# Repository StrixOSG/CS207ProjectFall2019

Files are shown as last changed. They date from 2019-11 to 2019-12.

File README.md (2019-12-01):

# Improved Soil Moisture Sensor [v1.0]

<p align="center">
  <a href="#repository-contents">Repository Contents</a> •
  <a href="#materials">Materials</a> •
  <a href="#software-requirements">Software Requirements</a> •
  <a href="#build-instructions">Build Instructions</a> •
  <a href="#usage">Usage</a> •
  <a href="#video">Video</a> •
  <a href="#team">Team</a> •
  <a href="#credits">Credits</a>
</p>

<p align="center">
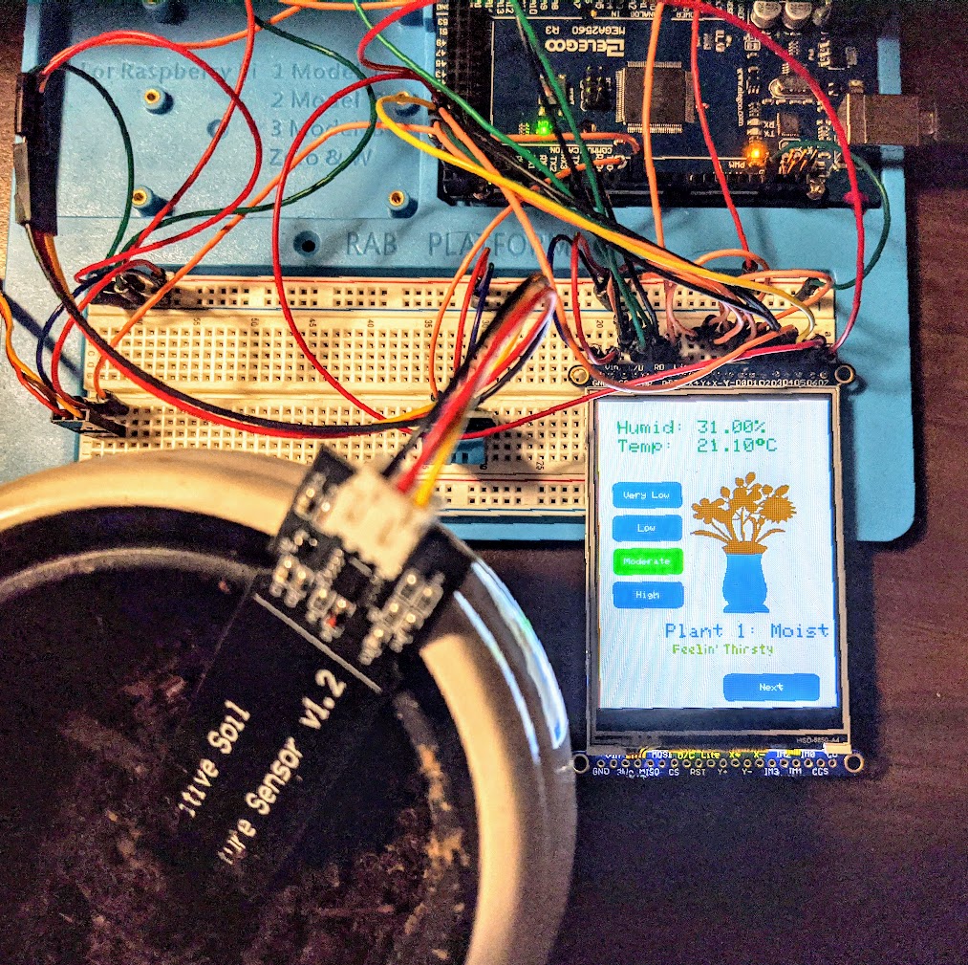
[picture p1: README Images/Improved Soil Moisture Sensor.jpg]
 
</p>

This project aims at making the soil moisture sensor project more practical (not necessarily cheaper) than the traditional (or original as I'll refer to it) project that has been done many times with a few LED indicators. To try and improve it, the LEDs are replaced by a 3.2" touchscreen display that can switch between plants depending on the amount of soil moisture sensors connected. Additionally, it can display the approximate temperature and humidity of the room as well as auto-water your plant by tipping over a small cup of water when attached to the servo. The touchscreen displays the temperature, humidity, and current soil moisture level of the plants, indicated by the 4 status' Wet, Damp, Moist, and Dry and an image of a plant that becomes more or less blue depending on the status. 

Repository Contents
============
* **/Bitmap Images** - Contains the .BMP files that were converted to code and used in the project and .psd (Photoshop CS6) files have been included for easy of modification if you desire to do so
* **/Hardware Diagrams** - .fzz (Fritzing files) and .jpg's that show the hardware and how it was wired
* **/Source Code** - Includes 2 folders, the original project that was built first as a test and the improved project
  * **/Source Code/ImprovedSoilMoistureSensor** - Contains the .cpp and .c files needed to run the improved project
  * **/Source Code/OriginalSoilMoistureSensor** - Contains the .cpp and .c files needed to run the original project

Materials
=========
**Original Project:**
* 1 x [Arduino UNO R3](https://store.arduino.cc/usa/arduino-uno-rev3)
* 4 x 220ohm Resistors
* 4 x LEDs (2 Green and 2 Red, or some way to differentiate Wet or Dry)

**Improved Project:**
* 1 x [3.2” TFT LCD with Touchscreen Breakout Board w/microSD socket](https://www.adafruit.com/product/1743)
* 1 x SG90 Micro Servo
* 1 x Small Plastic Cup (I just used a junior red solo cup)
* 1 x Servo Attachment (To tip the cup and not spill water everywhere)
* 1 x [Elegoo MEGA 2560 R3](https://www.amazon.ca/gp/product/B01H4ZLZLQ) (Note: An Arduino instead of an Elegoo will work, it's just more expensive)
* 1 x DHT11 (Temperature & Humidity Sensor)

**Materials In Common:**
* Several Jumper Wires (20 - 40)
* Breadboard
* 2 x [Capacitive Soil Moisture Sensors v1.2](https://www.amazon.ca/gp/product/B07H3P1NRM/ref=ppx_yo_dt_b_asin_title_o04_s00?ie=UTF8&psc=1)
* Several Male Header Pins

I bought a [ELEGOO UNO Project Super Starter Kit](https://www.amazon.ca/Elegoo-Project-Starter-Tutorial-Arduino/dp/B01D8KOZF4), which contained a lot of the components such as the Jumper Wires, Breadboard, Header Pins, DHT11, SG90 Micro Servo, Resistors, UNO R3, and LEDs.

Software Requirements
============

### Original Project:
None yay!

### Improved Project:
**Arduino Libraries:**
* Wire - Standard Library (just include it)
* Servo - Standard Library (just include it)
* [Adafruit GFX](https://github.com/adafruit/Adafruit-GFX-Library) 
* [Adafruit TFTLCD](https://github.com/adafruit/TFTLCD-Library)
* [Adafruit Touchscreen](https://github.com/adafruit/Adafruit_TouchScreen)
* [Adafruit DHT](https://github.com/adafruit/DHT-sensor-library)

**Software:**
  * [Img2Code](https://github.com/ehubin/Adafruit-GFX-Library/tree/master/Img2Code) - Adafruit Java Application that allows you to convert from a BMP image to code.
    * Resource on how to use it - [Electronics Lab Tutorial](https://www.electronics-lab.com/project/display-custom-bitmap-graphics-on-an-arduino-touch-screen-and-other-arduino-compatible-displays/)
    * I had some issues running this program (on Windows at least). I had to create a gradle.properties file in the Img2Code folder downloaded from the GitHUb, and point it to my JDK with "org.gradle.java.home=C:\\Program Files\\Java\\jdk1.8.0_191". After this, I ran the ./gradlew build and then ./gradlew run in the cmd prompt in the Img2Code directory and it worked. If you run into problems, the GitHub doesn't tell you any of this though, so if there is any other software for converting from a BMP image to code then don't be afraid to try it.

Build Instructions
==================
### Original Project:
For this project, you can use an UNO or a Mega. Fair warning that this project does not translate very well to the improved version. The point of setting this project up is to test the Mega, and the Soil Moisture Sensors and establish some simpler code to work off of.

#### Wiring:
* Wire the negative legs of the green LEDs to digital pins 3 and 5, and the red LEDs to digital pins 2 and 4. 
* Having some resistors (220ohm) connected to each of the positive legs of the LEDs is a good idea, just so they don't burn out as fast. The other side of the resistor should go to ground.
* The AOUT (Analog Out) pins on the soil moisture sensors should be connected to pins A0 and A1. Then the VCC's to 5V, and GND's to the GND.
* More details including diagrams (except for the above specified digital and analog pins to connect to) can be found [here](https://www.elithecomputerguy.com/2019/07/soil-moisture-sensor-led-alert-with-arduino-uno/), where the project was originally obtained from. Code for the idea of splitting the soil moisture values into 4 (Dry, Damp, Moist, and Dry) can be found [here](https://github.com/GadgetReboot/Arduino/blob/master/Uno/SSD1306_Soil_Meter/SSD1306_Soil_Meter.ino)

### Improved Project:
Now we get into the improvements. Like I mentioned in the Original Project's build instructions, almost everything changes except that we use the Mega and Soil Moisture Sensors.

#### Part Setup & Prep Work:
* The first step, is to solder on some male header pins to the 8-bit side of the 3.2" TFT Touchscreen. Be careful that it's not the SPI (Serial Peripheral Interface) side. [Adafruit](https://learn.adafruit.com/adafruit-2-dot-8-color-tft-touchscreen-breakout-v2/pinouts) has great detailed information about the differences between the two, but essentially it comes down to speed and how many pins you have. Since we have the Mega, we don't have to worry about using more pins so 8-bit mode is what is used for this project. SPI uses less pins, but it's 2 - 4 times slower than 8-bit mode at updating the touchscreen display.
  * Note: One problem encountered was that the pins weren't soldered well enough, which caused some issues when testing if the touchscreen was connected and working.

<p align="center">
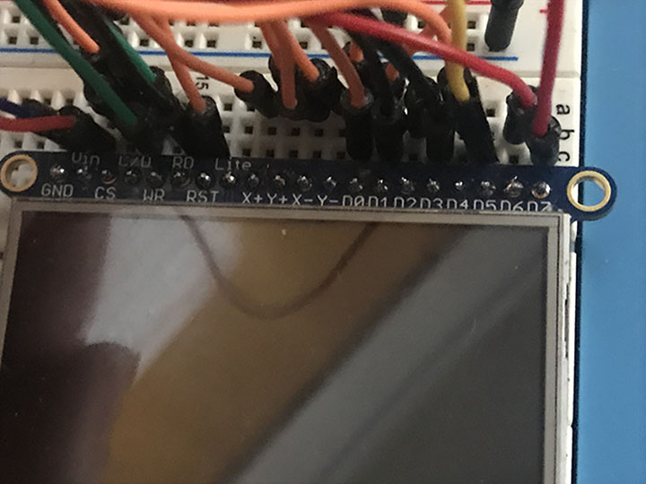
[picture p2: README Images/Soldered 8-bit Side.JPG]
 
</p>

* Next, the servo needs 3 male header pins.
* Lastly, attach a servo attachment to a junior red solo cup. I suggest zip ties and glue to ensure that the attachment stays in-place, so it remains securely attached to the cup while being tipped. Then attach the servo to some vertical base so that you don't have to hold it while it tips the cup. I attached it to a swiss rolls dessert box that I weighted down by again zip tying it to the box. This part needs improvement, because in the demo video you'll notice it begins to slip when filling the cup up with water.

<p align="center">
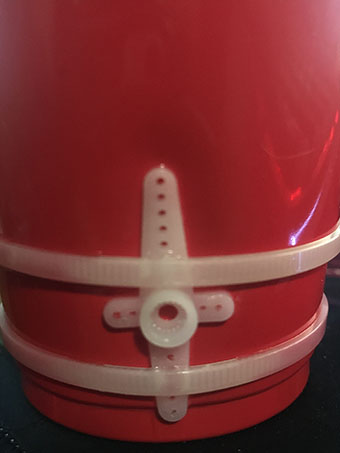
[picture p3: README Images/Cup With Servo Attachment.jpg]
 
</p>

#### Wiring:
* There isn't anything special with the wiring, except where the pins go. Just in case the Fritzing diagrams below aren't clear enough to follow here's the pins:

* Touchscreen (8-bit mode):
    * D0,XP to digital pin 22
    * D1,YM to digital pin 23
    * D2 to digital pin 24
    * D3 to digital pin 25
    * D4 to digital pin 26
    * D5 to digital pin 27
    * D6 to digital pin 28
    * D7 to digital pin 29
    * CS,YP to analog pin 3
    * C/D,XM to analog pin 2
    * WR to analog pin 1
    * RD to analog pin 0
    * RST to reset pin
    
    * Soil Moisture Sensors to analog pins 6 and 7
    * Temp & Humidity Sensor to digital pin 2
    * Servo to digital pin 3

* WARNING: Adafruit's tutorial states that the RST Pin can be A4 or another pin, but in my case this caused the touchscreen to not be read properly, so I connected it to the reset pin on the Mega.
* The XP, YM, YP, XM are the touchscreen's resistive sensor pins (detects touch) and they are to be connected to D0, D1, C/D, and CS respectively, so they all go to the same pins, 22, 23, A3, and A2 respectively.
* The soil moisture sensor, we setup in the original project, it is the same except which analog pins it connects to. 
* The servo's red wire goes to 5v, and black to GND. 
* The DHT11 (temp & humidity) sensor can be either 4 or 3 pins, if it does have 4 (unlike the one used in the project) then ignore one of the pins (search for your sensors pin layout to determine which pin this is). On the 3 pin sensor for this project, the ground is the right pin, middle is the data pin, and the left is the ground.

**Breadboard Diagram**

<p align="center">
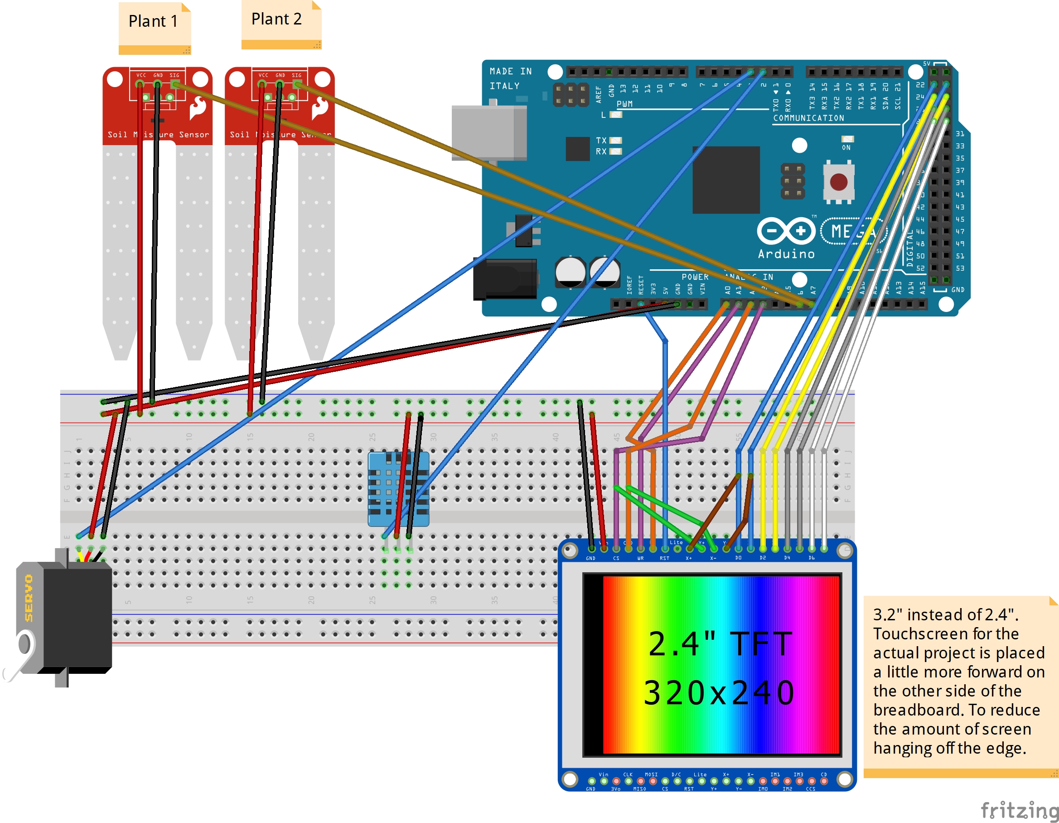
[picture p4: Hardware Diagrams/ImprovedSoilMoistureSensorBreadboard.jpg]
 
</p>

**Schematic Diagram**

<p align="center">
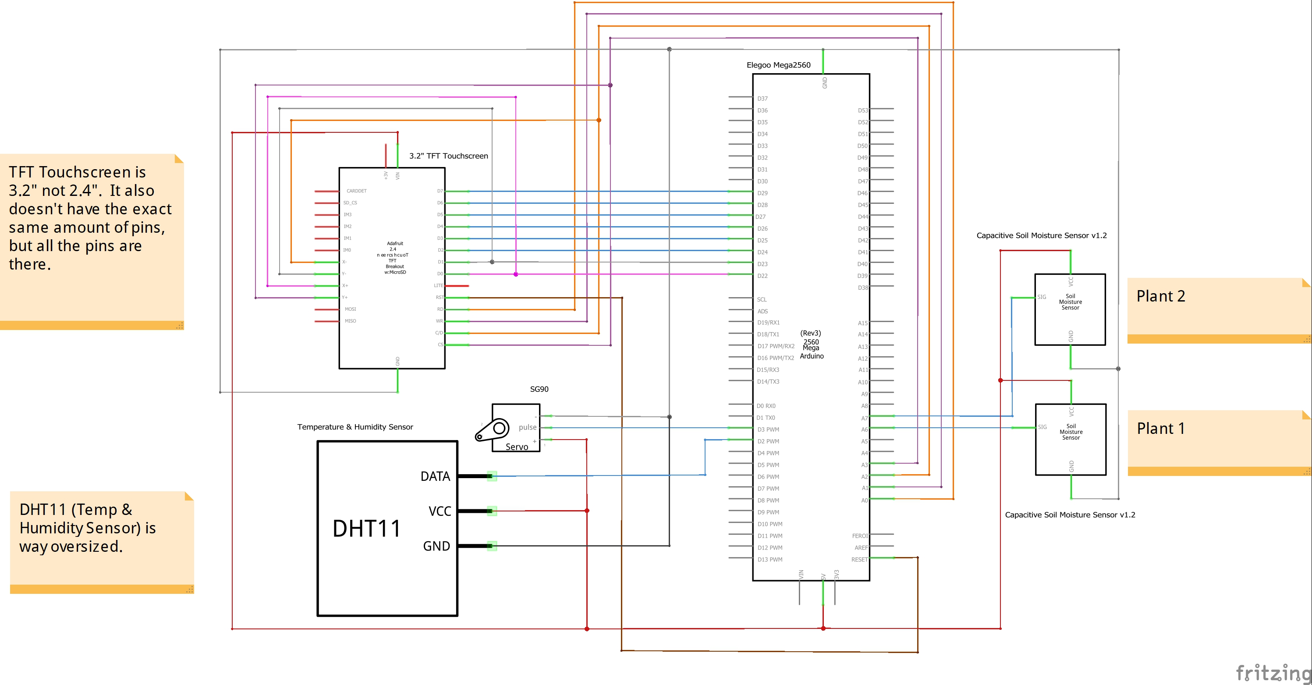
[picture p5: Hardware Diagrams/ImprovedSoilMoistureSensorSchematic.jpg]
 
</p>

Usage
=====
First step is to ensure that everything is wired and built properly.

### Original Project:
 1. Download the [original soil moisture sensor project folder](https://github.com/mattiasjahnke/arduino-projects).
 2. Open it in Arduino and run it on the device.
 3. Place soil moisture sensors in plants. Or grasp one of the soil moisture sensors in your hand and eventually the green LED should turn on, because your hand is damp or moist instead of dry when its not in anything.

### Improved Project:
 1. Download the [improved soil moisture sensor project folder](https://github.com/mattiasjahnke/arduino-projects).
 2. Open it in Arduino and run it on the device.
 3. Temperature and Humidity should be visible at the top of the screen.
 4. The visual state (partial or fully blue plant image) and text state (Wet, Damp, Moist, Dry) of the soil should be visible in the middle right of the screen. This changes based on how wet or dry the soil is.
 5. Plant moisture categories (Very Low, Low, Moderate, High) should be displayed on the left side of the screen, and status (I'm Drownin", "I'm Starting To Drown", "Tad too Much Water", "Ah. Just Right", "Feelin' Thirsty", "I NEED WATER SANDY", "I NEEEED ITTTT) should be below the soil moisture status.
 
  Note: Plant moisture categories can be found here: https://www.acurite.com/media/manuals/01410M-instructions.pdf
        0-20% (Very Low), 21-40% (Low), 41-60% (Moderate), 61-80+% (High)
        
 5. Tap the next button to switch to plant 2 (the other soil moisture sensor), and it's state should be displayed.
 6. The next button should disappear, and previous button should be on the other side of the screen.
 7. Changing the plant moisture category changes the status of your plant (if it needs more or less moisture). This is so it can be customized to fit the needs of your plant since not all plants require equal amounts of watering.
 8. Lastly, you can switch back and forth and monitor your plants water levels, and the temperature and humidity of the room :)

Video
=====

Improved Arduino Soil Moisture Sensor YouTube Video (http://www.youtube.com/watch?v=PviWJTjPKCI "Improved Arduino Soil Moisture Sensor - CS207 Fall 2019")

Team
=====
Mattthew Hamilton - I'm the only one on the team.

Credits
=======
* Jeff Bishop (A.K.A. Eli The Computer Guy) for inspiring the original project -  https://www.elithecomputerguy.com/2019/07/soil-moisture-sensor-led-alert-with-arduino-uno/

* Soil moisture sensor, mapping different moisture levels
  https://github.com/GadgetReboot/Arduino/blob/master/Uno/SSD1306_Soil_Meter/SSD1306_Soil_Meter.in
  Code by GitHub user: GadgetReboot

* Basic touchscreen code, setup, initialization, etc.
  https://github.com/adafruit/TFTLCD-Library
  Code by: Adafruit

* Bitmap image drawing code
  https://www.electronics-lab.com/project/display-custom-bitmap-graphics-on-an-arduino-touch-screen-and-other-arduino-compatible-displays/
  Code by: Nick Koumaris

* Button code
  https://learn.adafruit.com/arduin-o-phone-arduino-powered-diy-cellphone/arduin-o-phone-sketch
  Code by: Adafruit

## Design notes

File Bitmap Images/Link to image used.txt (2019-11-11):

Flower Vase - https://svgsilh.com/ff5722/image/147218.html

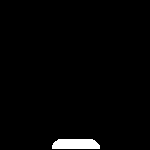
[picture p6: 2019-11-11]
Bitmap Images/SoilMoistureMeterDry.bmp

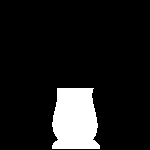
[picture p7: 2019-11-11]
Bitmap Images/SoilMoistureMeterMoist.bmp

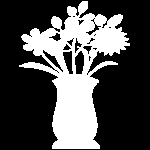
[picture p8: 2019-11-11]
Bitmap Images/SoilMoistureMeterBackground.bmp

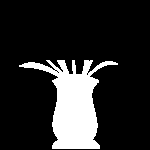
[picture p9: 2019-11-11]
Bitmap Images/SoilMoistureMeterDamp.bmp

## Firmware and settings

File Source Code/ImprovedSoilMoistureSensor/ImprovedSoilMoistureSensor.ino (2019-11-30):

/*

Project Summary:
This program will read the analog moisture level of
2 capactive soil moisture sensors, and a digital
temperature and humidity sensor. It then outputs
these readings to a touch screen, and there are buttons
to switch bettween the two plants (soil moisture sensors).
A servo is also attached that will tip a cup to fill one
of the plants with water if it needs it.

Parts:
- 2 x Soil moisture sensors
- 1 x 3.2" TFT Resistive Touchscreen
- 1 x DH11 Temp & Humidity Sensor
- 1 x SG90 Servo

Connections: 
- Touchscreen (8-bit mode):
    D0,XP to digital pin 22
    D1,YM to digital pin 23
    D2 to digital pin 24
    D3 to digital pin 25
    D4 to digital pin 26
    D5 to digital pin 27
    D6 to digital pin 28
    D7 to digital pin 29
    C/D,YP to analog pin 3
    CS,XM to analog pin 2
    WR to analog pin 1
    RD to analog pin 0
    RST to reset pin
    
- Soil Moisture Sensors to anlog pins 6 and 7
- Temp & Humidity Sensor to digital pin 2
- Servo to digital pin 3


Some code copied from: 
  Soil moisture sensor, mapping different moisture levels
  https://github.com/GadgetReboot/Arduino/blob/master/Uno/SSD1306_Soil_Meter/SSD1306_Soil_Meter.in
  Code by GitHub user: GadgetReboot

  Basic touchscreen code, setup, initializattion, etc.
  https://github.com/adafruit/TFTLCD-Library
  Code by: Adafruit

  Bitmap image drawing code
  https://www.electronics-lab.com/project/display-custom-bitmap-graphics-on-an-arduino-touch-screen-and-other-arduino-compatible-displays/
  Code by: Nick Koumaris

  Button code
  https://learn.adafruit.com/arduin-o-phone-arduino-powered-diy-cellphone/arduin-o-phone-sketch
  Code by: Adafruit

Modified by: Matthew Hamilton
Date Modified: Nov.10, 2019
*/

/////////////////////   BEGIN TOUCHSCREEN   /////////////////////////////////////////
#include <Wire.h>
#include <Adafruit_GFX.h>    // Core graphics library
#include <Adafruit_TFTLCD.h> // Hardware-specific library
#include <TouchScreen.h>
#include <Fonts/TomThumb.h>

//BMP Images
extern uint8_t soilMoistureMeterBackground[];
extern uint8_t soilMoistureMeterWet[];
extern uint8_t soilMoistureMeterMoist[];
extern uint8_t soilMoistureMeterDamp[];
extern uint8_t soilMoistureMeterDry[];

#if defined(__SAM3X8E__)
    #undef __FlashStringHelper::F(string_literal)
    #define F(string_literal) string_literal
#endif

#define YP A3               // must be an analog pin, use "An" notation!
#define XM A2               // must be an analog pin, use "An" notation!
#define YM 23               // can be a digital pin
#define XP 22               // can be a digital pin

#define TS_MINX 150
#define TS_MINY 120
#define TS_MAXX 920
#define TS_MAXY 940

#define MINPRESSURE 10
#define MAXPRESSURE 1000

// For better pressure precision, we need to know the resistance
// between X+ and X- Use any multimeter to read it
// For the one we're using, its 300 ohms across the X plate
TouchScreen ts = TouchScreen(XP, YP, XM, YM, 300);

#define LCD_CS A3
#define LCD_CD A2
#define LCD_WR A1
#define LCD_RD A0
// optional
#define LCD_RESET A4

// Assign human-readable names to some common 16-bit color values:
#define  BLACK   0x0000
#define BLUE    0x001F
#define RED     0xF800
#define GREEN   0x07E0
#define CYAN    0x07FF
#define MAGENTA 0xF81F
#define YELLOW  0xF7C2
#define WHITE   0xFFFF
#define ORANGE 0xFE62

#define PLANT_GREEN 0x0DE9
#define WATER 0x35FF
#define VASE_BACKGROUND 0xBBC1

Adafruit_TFTLCD tft(LCD_CS, LCD_CD, LCD_WR, LCD_RD, LCD_RESET);

#define BOXSIZE 40

#define TOTAL_BUTTONS 6
char buttonLabels[TOTAL_BUTTONS][15] = {"Next","Previous","Very Low","Low","Moderate","High"};
uint16_t buttonColors[2] = {WATER, GREEN};
Adafruit_GFX_Button buttons[TOTAL_BUTTONS];

/////////////////////   END TOUCHSCREEN   ///////////////////////////////////////////

/////////////////////   BEGIN SOIL MOISTURE SENSORS   ///////////////////////////////

const int SOIL_SENSOR_PINS[] = {A6, A7};  // soil moisture sensor pins
const int MAX_PLANTS = 2;
int validSoilSensorReadings[] = {0, 0};           // valid sensor analog reading to record
int soilSensorResults[] = {0, 0};                 // scaled sensor data [0..3] = [wet, damp, moist, dry]
int previousSoilSensorResult = -1;
int currentPlant = 0;

//Set the default plant moisture setting to Moderate (3)
int plantMoistureSetting[MAX_PLANTS] = {2, 2};

const int wetProbe      = 300;                // wet readings are around 1.5v or analog input value ~300
const int dryProbe      = 620;                // dry readings are around 3v or analog input value ~620

/////////////////////   END SOIL MOISTURE SENSORS   /////////////////////////////////

/////////////////////   BEGIN TEMPERATURE & HUMIDITY SENSORS   /////////////////////

#include "DHT.h"

#define TH_PIN 2
#define TH_TYPE DHT11

DHT dht(TH_PIN, TH_TYPE);

float humidity, celcius, fahrenheit, heatIndexC, heatIndexF;

/////////////////////    END TEMPERATURE & HUMIDITY SENSORS   ////////////////////

/////////////////////   BEGIN SERVO   ////////////////////////////////////////////

#include <Servo.h>

#define SERVO_PIN 3
int angle = 0;
int totalWateringTime = 5000;
int wateringBreakTime = 5000;
unsigned long wateringEndTime = 0;
unsigned long wateringStartTime = 0;
bool wateringBreak = false;
bool needsWater = false;
bool wateringStart = true;

Servo servo;

/////////////////////    END SERVO   /////////////////////////////////////////////

void setup() {
  
  Serial.begin(9600);

  SetupTouchscreen();

  //Setup temp & humidity sensor
  dht.begin();
  
}

void SetupTouchscreen(){

  tft.reset();

  uint16_t identifier = tft.readID();

  //Determine the type of touchscreen and if it's setup correctly
  if(identifier == 0x9325) {
    Serial.println(F("Found ILI9325 LCD driver"));
  } else if(identifier == 0x9328) {
    Serial.println(F("Found ILI9328 LCD driver"));
  } else if(identifier == 0x7575) {
    Serial.println(F("Found HX8347G LCD driver"));
  } else if(identifier == 0x9341) {
    Serial.println(F("Found ILI9341 LCD driver"));
  } else if(identifier == 0x8357) {
    Serial.println(F("Found HX8357D LCD driver"));
  } else {
    Serial.print(F("Unknown LCD driver chip: "));
    Serial.println(identifier, HEX);
    Serial.println(F("If using the Adafruit 2.8\" TFT Arduino shield, the line:"));
    Serial.println(F("  #define USE_ADAFRUIT_SHIELD_PINOUT"));
    Serial.println(F("should appear in the library header (Adafruit_TFT.h)."));
    Serial.println(F("If using the breakout board, it should NOT be #defined!"));
    Serial.println(F("Also if using the breakout, double-check that all wiring"));
    Serial.println(F("matches the tutorial."));
    return;
  }

  tft.begin(identifier);
  
  //Portrait
  tft.setRotation(2);

  //Screen background color
  tft.fillScreen(WHITE);

  CreateButtons();
  
}

void loop() {
    
  GetSoilMoistureSensorData();
  GetTHSensorData();
  DisplayDataOnTouchScreen();
  DetectTouch();
  AutoWaterWithServo();

}

void CreateButtons(){
  
  if(currentPlant < (MAX_PLANTS - 1)){
    
    //Next plant
    //initButton(Touchscreen, X, Y, Width, Height, outline, fill, text color, text, text size)
    buttons[0].initButton(&tft, 175, 300, 100, 30, WHITE, buttonColors[0], WHITE, buttonLabels[0], 1);
    buttons[0].drawButton();

  }

  if(currentPlant > 0){
    
    //Previous plant
    buttons[1].initButton(&tft, 75, 300, 100, 30, WHITE, buttonColors[0], WHITE, buttonLabels[1], 1);
    buttons[1].drawButton();

  }

  //Plant Categories
  
  //Very Low Moisture
  if(plantMoistureSetting[currentPlant] == 0){
    buttons[2].initButton(&tft, 50, 100, 75, 30, WHITE, buttonColors[1], WHITE, buttonLabels[2], 1);
  }else{
    buttons[2].initButton(&tft, 50, 100, 75, 30, WHITE, buttonColors[0], WHITE, buttonLabels[2], 1);
  }
  buttons[2].drawButton();
  
  //Low Moisture
  if(plantMoistureSetting[currentPlant] == 1){
    buttons[3].initButton(&tft, 50, 135, 75, 30, WHITE, buttonColors[1], WHITE, buttonLabels[3], 1);
  }else{
    buttons[3].initButton(&tft, 50, 135, 75, 30, WHITE, buttonColors[0], WHITE, buttonLabels[3], 1);
  }
  buttons[3].drawButton();
  
  //Moderate Moisture
  if(plantMoistureSetting[currentPlant] == 2){
    buttons[4].initButton(&tft, 50, 170, 75, 30, WHITE, buttonColors[1], WHITE, buttonLabels[4], 1);
  }else{
    buttons[4].initButton(&tft, 50, 170, 75, 30, WHITE, buttonColors[0], WHITE, buttonLabels[4], 1);
  }
  buttons[4].drawButton();
  
  //High Moisture
  if(plantMoistureSetting[currentPlant] == 3){
    buttons[5].initButton(&tft, 50, 205, 75, 30, WHITE, buttonColors[1], WHITE, buttonLabels[5], 1);
  }else{
    buttons[5].initButton(&tft, 50, 205, 75, 30, WHITE, buttonColors[0], WHITE, buttonLabels[5], 1);
  }
  buttons[5].drawButton();
  
}

void DetectTouch(){

  TSPoint point = ts.getPoint();
  
  pinMode(XM, OUTPUT);
  pinMode(YP, OUTPUT);

  //If touch has been detected
  if(point.z > MINPRESSURE && point.z < MAXPRESSURE){

      // scale from 0->1023 to tft.width
      point.x = map(point.x, TS_MINX, TS_MAXX, 0, tft.width());
      point.y = map(point.y, TS_MINY, TS_MAXY, 0, tft.height());

      Serial.print("X: ");
      Serial.println(point.x);
      Serial.print("Y: ");
      Serial.println(point.y);
      
    //Detect if button pressed
    for (int i = 0; i < TOTAL_BUTTONS; i++) {
        
        if(buttons[i].contains(point.x, point.y)) {

           HandleButtons(i);
          
        }

      }
      
  }

}

void HandleButtons(int buttonNumber){

  switch(buttonNumber){

    case 0: //Next Plant
      if(currentPlant < (MAX_PLANTS - 1)){
    
        currentPlant++;
        Serial.println(currentPlant);
    
      }
    break;
   case 1:  //Previous plant
      if(currentPlant > 0){
      
        currentPlant--;
        Serial.println(currentPlant);
        
      }
      break;
    case 2: //Very Low Moisture
      plantMoistureSetting[currentPlant] = 0;
      break;
    case 3: //Low Moisture
      plantMoistureSetting[currentPlant] = 1;
      break;
    case 4: //Moderate Moisture
      plantMoistureSetting[currentPlant] = 2;
      break;
    case 5: //Moderate Moisture
      plantMoistureSetting[currentPlant] = 3;
      break;
      
  }

  //Some button was tapped so wipe the screen and redraw the buttons
  ResetTouchScreen();
  CreateButtons();
  
}

void DisplayDataOnTouchScreen(){

  tft.setTextSize(2);
  tft.setCursor(68, 235);
  tft.setTextColor(WATER, WHITE);
  DisplaySoilMoistureData();

  tft.setFont();
  tft.setTextSize(2);
  tft.setCursor(20, 20);
  tft.setTextColor(PLANT_GREEN, WHITE);
  DisplayHumidityData();
  tft.setCursor(20, 40);
  DisplayTempData();
  
}

void DisplaySoilMoistureData(){

  tft.print(F("Plant "));
  tft.print(currentPlant + 1);
  tft.print(F(": "));

  if(previousSoilSensorResult != soilSensorResults[currentPlant]){
    
    drawBitmap(75, 75, soilMoistureMeterBackground, 150, 150, VASE_BACKGROUND);
    previousSoilSensorResult = soilSensorResults[currentPlant];
    DisplaySoilSensorResultOnScreen(soilSensorResults[currentPlant]);

  }
  
}

void ResetTouchScreen(){

  tft.fillScreen(WHITE);
  previousSoilSensorResult = -1;
  
}

void DisplayTempData(){

  tft.print("Temp:  ");
  DisplayCelcius();
  //DisplayFahrenheit();
  
}

void DisplayCelcius(){

  tft.print(celcius);
  tft.print((char)247); //Degrees symbol
  tft.println("C");
  
}

void DisplayFahrenheit(){

  tft.print(fahrenheit);
  tft.print((char)247); //Degrees symbol
  tft.println("F");
  
}

void DisplayHumidityData(){

  tft.print("Humid: ");
  tft.print(humidity);
  tft.print("% ");
  
}

void DisplayHeatIndexData(){
  
  tft.print("Heat index: ");
  tft.print(heatIndexC);
  tft.print((char)247); //Degrees symbol
  tft.println("C");
  tft.print(heatIndexF);
  tft.print((char)247); //Degrees symbol
  tft.println("F");
  
}

void AutoWaterWithServo(){

  //If Dry or currently watering
  if(needsWater){

    if(!wateringBreak || (millis() > (wateringEndTime + wateringBreakTime))){

      //If just starting to water
      if(wateringStart){
  
        wateringStartTime = millis();
        wateringStart = false;
        wateringBreak = false;

        servo.attach(SERVO_PIN);
  
        //Tilt the servo to 120 (tip the cup to water the plant)
        for(;angle < 120; angle++)  
        {                           
          servo.write(angle);               
          delay(15);                   
        }

        servo.detach();
        
      }
  
      //If watering time is up
      if(millis() > (wateringStartTime + totalWateringTime)){

          servo.attach(SERVO_PIN);
          
          // Reset the servo to 0 (tilt the cup back upright)
          for(angle = 120; angle > 0; angle--)    
          {                                
            servo.write(angle);           
            delay(15);       
          }

          servo.detach();
          
          wateringStartTime = 0;
          wateringEndTime = millis();
          wateringBreak = true;
          wateringStart = true;
          needsWater = false;
  
      }
      
    }
    
  }
  
}

void GetTHSensorData(){

  humidity = dht.readHumidity();
  celcius = dht.readTemperature();
  fahrenheit = dht.readTemperature(true);

   if (isnan(humidity) || isnan(celcius) || isnan(fahrenheit)) {
    
    Serial.println(F("Error getting readings from DHT11 sensor!"));
    return;
    
  }

  heatIndexC = dht.computeHeatIndex(celcius, humidity, false);
  heatIndexF = dht.computeHeatIndex(fahrenheit, humidity);

  /*Serial.print(F("Humidity: "));
  Serial.print(humidity);
  Serial.print(F("%  Temperature: "));
  Serial.print(celcius);
  Serial.print(F("°C "));
  Serial.print(fahrenheit);
  Serial.print(F("°F  Heat index: "));
  Serial.print(heatIndexC);
  Serial.print(F("°C "));
  Serial.print(heatIndexF);
  Serial.println(F("°F"));*/
  
}

void GetSoilMoistureSensorData(){

  //Do this for both soil moisture sensors and pairs of LEDs
  for(int i = 0; i < MAX_PLANTS; i++){

    int moistureValue = analogRead(SOIL_SENSOR_PINS[i]);
    //Serial.println(moistureValue);
  
    //If there is a difference
    if (abs(validSoilSensorReadings[i] - moistureValue) > 10) {
      validSoilSensorReadings[i] = moistureValue;
    }
    
    soilSensorResults[i] = map(validSoilSensorReadings[i], dryProbe, wetProbe, 0, 100);  // scale analog input to a smaller range for wet to dry

  }
  
}

void DisplaySoilSensorResultOnScreen(int result){
  
  // display the correct soil moisture level on the display
  // lower voltages represent more wet levels
    if(result > 60 && result <= 100){
      tft.println(F("Wet  "));
      drawBitmap(75, 75, soilMoistureMeterWet, 150, 150, WATER);

      tft.setCursor(75, 260);
      tft.fillRect(75, 255, 200, 20, WHITE);
      tft.setFont(&TomThumb);
      tft.setTextSize(2);
      switch(plantMoistureSetting[currentPlant]){
        case 0:
          tft.setTextColor(RED, WHITE);
          tft.println(F("I'm Drownin'"));
          break;
        case 1:
          tft.setTextColor(ORANGE, WHITE);
          tft.println(F("I'm Starting To Drown"));
          break;
        case 2:
          tft.setTextColor(YELLOW, WHITE);
          tft.println(F("Tad too Much Water"));
          break;
        case 3:
          tft.setTextColor(GREEN, WHITE);
          tft.println(F("Ah. Just Right"));
          break;
      }
      
    }
    else if(result > 40 && result < 61){
      tft.println(F("Damp "));
      drawBitmap(75, 75, soilMoistureMeterDamp, 150, 150, WATER);

      tft.setCursor(75, 260);
      tft.fillRect(75, 255, 200, 20, WHITE);
      tft.setFont(&TomThumb);
      tft.setTextSize(2);
      switch(plantMoistureSetting[currentPlant]){
        case 0:
          tft.setTextColor(ORANGE, WHITE);
          tft.println(F("I'm Starting To Drown"));
          break;
        case 1:
          tft.setTextColor(YELLOW, WHITE);
          tft.println(F("Tad too Much Water"));
          break;
        case 2:
          tft.setTextColor(GREEN, WHITE);
          tft.println(F("Ah. Just Right"));
          break;
        case 3:
          tft.setTextColor(YELLOW, WHITE);
          tft.println(F("Feelin' Thirsty"));
          break;
      }
      
    }
    else if(result > 20 && result < 41){
      tft.println(F("Moist"));
      drawBitmap(75, 75, soilMoistureMeterMoist, 150, 150, WATER);

      tft.setCursor(75, 260);
      tft.fillRect(75, 255, 200, 20, WHITE);
      tft.setFont(&TomThumb);
      tft.setTextSize(2);
      switch(plantMoistureSetting[currentPlant]){
        case 0:
          tft.setTextColor(YELLOW, WHITE);
          tft.println(F("Tad too Much Water"));
          break;
        case 1:
          tft.setTextColor(GREEN, WHITE);
          tft.println(F("Ah. Just Right"));
          break;
        case 2:
          tft.setTextColor(YELLOW, WHITE);
          tft.println(F("Feelin' Thirsty"));
          break;
        case 3:
          tft.setTextColor(ORANGE, WHITE);
          tft.println(F("I NEED WATER SANDY"));
          needsWater = true;
          break;
      }
      
    }
    else{
      tft.println(F("Dry  "));
      drawBitmap(75, 75, soilMoistureMeterDry, 150, 150, WATER);

      tft.setCursor(75, 260);
      tft.fillRect(75, 255, 200, 20, WHITE);
      tft.setFont(&TomThumb);
      tft.setTextSize(2);
      switch(plantMoistureSetting[currentPlant]){
        case 0:
          tft.setTextColor(GREEN, WHITE);
          tft.println(F("Ah. Just Right"));
          break;
        case 1:
          tft.setTextColor(YELLOW, WHITE);
          tft.println(F("Feelin' Thirsty"));
          break;
        case 2:          
          tft.setTextColor(ORANGE, WHITE);
          tft.println(F("I NEED WATER SANDY"));
          needsWater = true;
          break;
        case 3:
          tft.setTextColor(RED, WHITE);
          tft.println(F("I NEEEED ITTTT"));
          needsWater = true;
          break;
      }
      
    }

}

void drawBitmap(int16_t x, int16_t y,
 const uint8_t *bitmap, int16_t w, int16_t h, uint16_t color) {
  int16_t i, j, byteWidth = (w + 7) / 8;
  uint8_t byte;
  for(j=0; j<h; j++) {
    for(i=0; i<w; i++) {
      if(i & 7) byte <<= 1;
      else      byte   = pgm_read_byte(bitmap + j * byteWidth + i / 8);
      if(byte & 0x80) tft.drawPixel(x+i, y+j, color);
    }
  }
}

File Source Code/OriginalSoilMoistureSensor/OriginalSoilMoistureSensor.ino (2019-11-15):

/*

Project Summary:
This program will read the analog moisture level of
2 capactive soil moisture sensors, and output whether 
it's dry, moist, damp, or wet.

Project Idea & Components From: 
Jeff Bishop (Eli The Computer Guy)

Parts:
- 4 x LEDs (2 green, 2 red)
- 4 x 220ohm resistors
- 2 x Soil moisture sensors

Connections: 
- Green LEDs on pins 3 and 5
- Red LEDs on pins 2 and 4
- Soil moisture sensors on pins A0 and A1

Some code copied from: 
https://github.com/GadgetReboot/Arduino/blob/master/Uno/SSD1306_Soil_Meter/SSD1306_Soil_Meter.ino
Code by GitHub user: GadgetReboot
Date Created: Sept.6, 2018

Modified by: Matthew Hamilton
Date Modified: Oct.29, 2019
*/

int const SENSOR_AMT = 2;

int greenLEDS[] = {3, 5};
int redLEDS[] = {2, 4};
int moistureSensorPins[] = {A0, A1}; // soil moisture sensor pins
int validSensorReadings[] = {0, 0};   // valid sensor analog reading to record
int sensorResults[] = {0, 0};         // scaled sensor data [0..3] = [wet, damp, moist, dry]

const int wetProbe      = 300;   // wet readings are around 1.5v or analog input value ~300
const int dryProbe      = 620;   // dry readings are around 3v or analog input value ~620

void setup() {

  Serial.begin(9600);

  for(int i = 0; i < SENSOR_AMT; i++){
  
    pinMode(greenLEDS[i], OUTPUT);
    pinMode(redLEDS[i], OUTPUT);

  }

}

void loop() {

  //Do this for both soil moisture sensors and pairs of LEDs
  for(int i = 0; i < SENSOR_AMT; i++){

    int moistureValue = analogRead(moistureSensorPins[i]);
    Serial.println(moistureValue);
  
    //If there is a difference
    if (abs(validSensorReadings[i] - moistureValue) > 10) {
      validSensorReadings[i] = moistureValue;
    }
    
    sensorResults[i] = map(validSensorReadings[i], wetProbe, dryProbe, 0, 4);  // scale analog input to a smaller range for wet to dry
  
    //Output values to Serial Log
    Serial.print("Sensor  ");
    Serial.print(i);
    Serial.print(": ");
    DisplaySensorResult(sensorResults[i]);
  
    //Change LED colours
    if(sensorResults[i] >= 2){
  
      digitalWrite(greenLEDS[i], LOW);
      digitalWrite(redLEDS[i], HIGH);
      
    }else{
  
      digitalWrite(greenLEDS[i], HIGH);
      digitalWrite(redLEDS[i], LOW);
      
    }

  }
  
  delay(500);

}

void DisplaySensorResult(int result){
  
  // display the correct soil moisture level on the display
  // lower voltages represent more wet levels
  switch (result) {
    case 0:
      Serial.println("Wet");
      break;
    case 1:
      Serial.println("Damp");
      break;
    case 2:
      Serial.println("Moist");
      break;
    case 3:
      Serial.println("Dry");
      break;
    case 4:    // same as case 3, due to how map works.
      Serial.println("Dry");
      break;
  }

}

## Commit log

2019-10-30 Original Soil Moisture Sensor Code Completed
    The original soil moisture sensor is based on two videos. One is EliTheComputerGuy who had LEDs to indicate wet or dry and the other is GadgetReboot who split the sensor values into wet, damp, moist,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
2019-10-31 Refactored code
    Instead of doing everything twice, used arrays with two values each (e.g., 2 green leds, 2 red, 2 moisture sensors, etc.), which cut down on redundant code in the loop function.
2019-11-10 Setup & Test Code for New Components
    Code to setup the touchscreen, soil moisuture sesnors, temp & humidity sensors, and servo has been added. Added a description of the project, parts, connections, and borrowed code. Additionally imple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
2019-11-10 Sensor data is being printed on the touchscreen
    Soil moisture, temperature, and humidity all are displayed with text on the touchscreen. Also figured out the character code to display the degrees symbol on the touchscreen.
2019-11-11 Added BMP images for water level meter and cleaned up display
    There are now 5 BMP images for the water level. One is the background vase, the others are the 4 water levels that can be colored in blue (Wet, Damp, Moist, Dry). Background is now white, and the moi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
2019-11-11 Added buttons to switch plant profiles.
    Added next and previous buttons for switching between plant profiles. More buttons can easily be added.
2019-11-11 Added servo code for autowatering.
    If the current plant is dry then the servo will rotate the attached cup to water the plant.
2019-11-14 Made fritzing diagrams
    Created fritzing files and images to represent as closely as possible, the hardware used and the wiring layout.
    [ImprovedSoilMoistureSensorBreadboard.fzz, ImprovedSoilMoistureSensorSchematic.fzz]
2019-11-14 Created a Code Folder, and Renamed the Images Folder
    Moved the arduino project folders into a code folder for better organization, and renamed the images folder to Bitmap Images to more accurately reflect what it's for.
2019-11-14 Renamed folders again
    The folder names more closely match Trevor's suggested folder names in his GitHub example.
    [ImprovedSoilMoistureSensorBreadboard.fzz, ImprovedSoilMoistureSensorSchematic.fzz]
2019-11-15 Added Materials and Requirements Section
2019-11-15 Added links to purchase materials
2019-11-15 Update Soldered 8-bit Side.JPG
2019-11-15 Image of Cup With Servo Attachment
2019-11-15 Picture of the Improved Soil Moisture Sensor
2019-11-15 Image of the Improved Soil Moisture Sensor Added
2019-11-17 Added buttons for moisture categories and changed moisture functionality
    Very Low, Low, Moderate, and High moisture category buttons have been added to the screen and remember what was pressed for each plant. If selected, it has a green background. Functionality for deter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
2019-11-27 Fixed CS and C/D pin layout
    CS and C/D were reversed in the wiring description (not the diagrams)
2019-11-30 Servo updates (late pushing the changes)
    These changes have been done for quite a while just forgot to push it to the GitHub. This update improves the auto-watering functionality.
